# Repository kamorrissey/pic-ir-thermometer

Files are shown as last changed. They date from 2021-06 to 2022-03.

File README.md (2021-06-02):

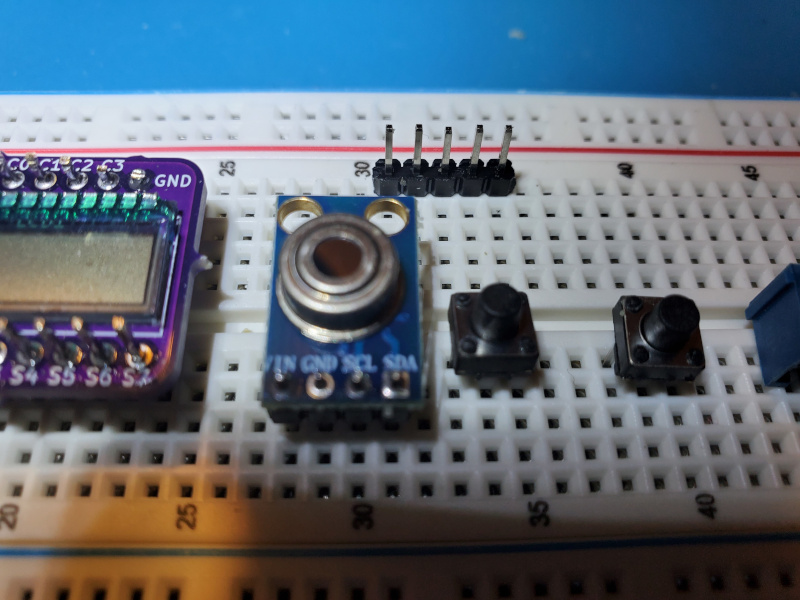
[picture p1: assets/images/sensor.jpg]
MLX90614 IR sensor on breadboard


# pic-ir-thermometer

(Under construction.
Circuit schematic is stable; PCB design to be provided.
Firmware mostly complete but does not yet read from temperature sensor or read/write EEPROM.
3d-printable, handheld enclosure design to be provided.)

Open-source hardware and firmware for a PIC16LF19156-driven IR non-contact thermometer using a Melexis MLX90614 sensor and Lumex LCD-S401M16KR LCD segment display.

This project demonstrates several major functions of a Microchip PIC microcontroller (MCU):
1. using the built-in LCD driver module to directly drive a multiplexed LCD segment display
2. using the I2C/IIC/SMBus interface (MSSP) to communicate with an external temperature sensor
3. using the timer (TMR2, TMR4) and configurable logic cell (CLC) modules to debounce switch inputs in hardware
4. using the timer module (TMR0) to detect timeout of user input
5. using the internal voltage reference (FVR) and analog-to-digital converter (ADC) modules to detect low-battery state with no external components required
6. using the built-in EEPROM to read and write persistent data

The firmware is written in C using the free version of the Microchip MPLAB X IDE and XC8 compiler.
As much code as practical is generated rather than hand-written
by using the Microchip Code Configurator (MCC) plugin-in to MPLAB.
The full MPLAB project is provided.

The hardware uses minimal parts.
The surface mount MOSFET for battery protection is optional.
The full KiCad project containing schematic and PCB design is provided.

A 3D-printable, handheld enclosure design holding a single AA cell is provided.
All needed STL files for printing the enclosure are provided.

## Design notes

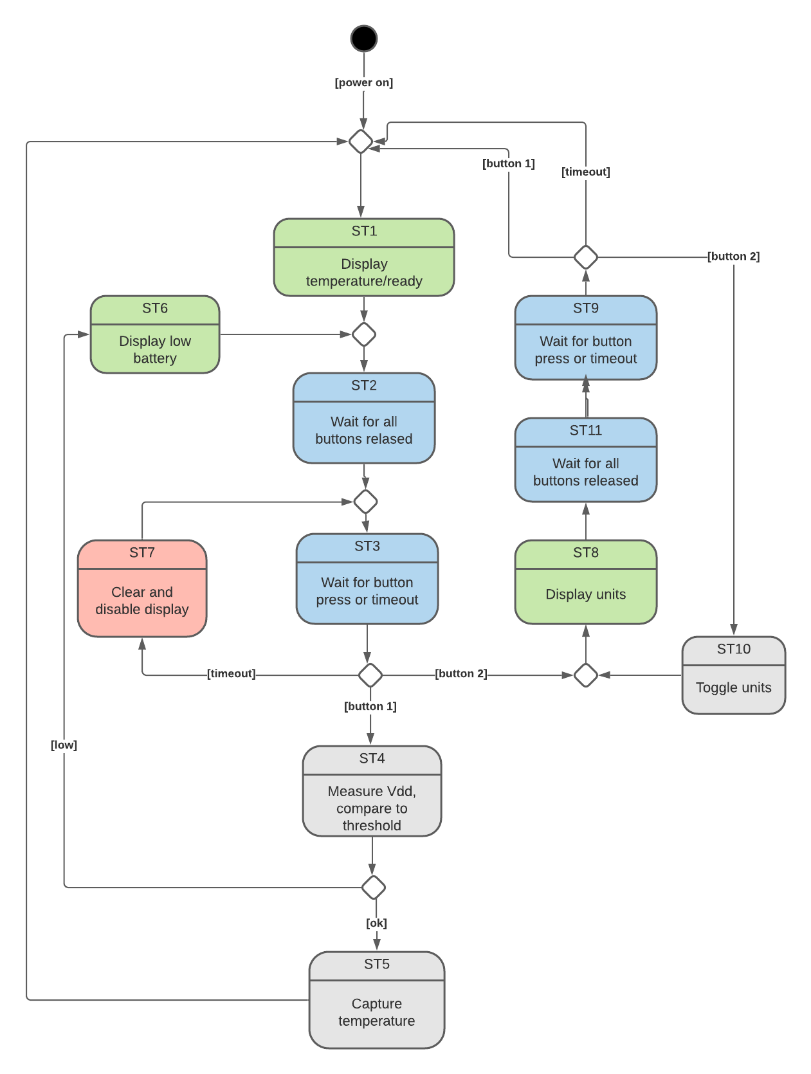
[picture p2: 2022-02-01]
assets/images/Thermometer_State_Diagram.png

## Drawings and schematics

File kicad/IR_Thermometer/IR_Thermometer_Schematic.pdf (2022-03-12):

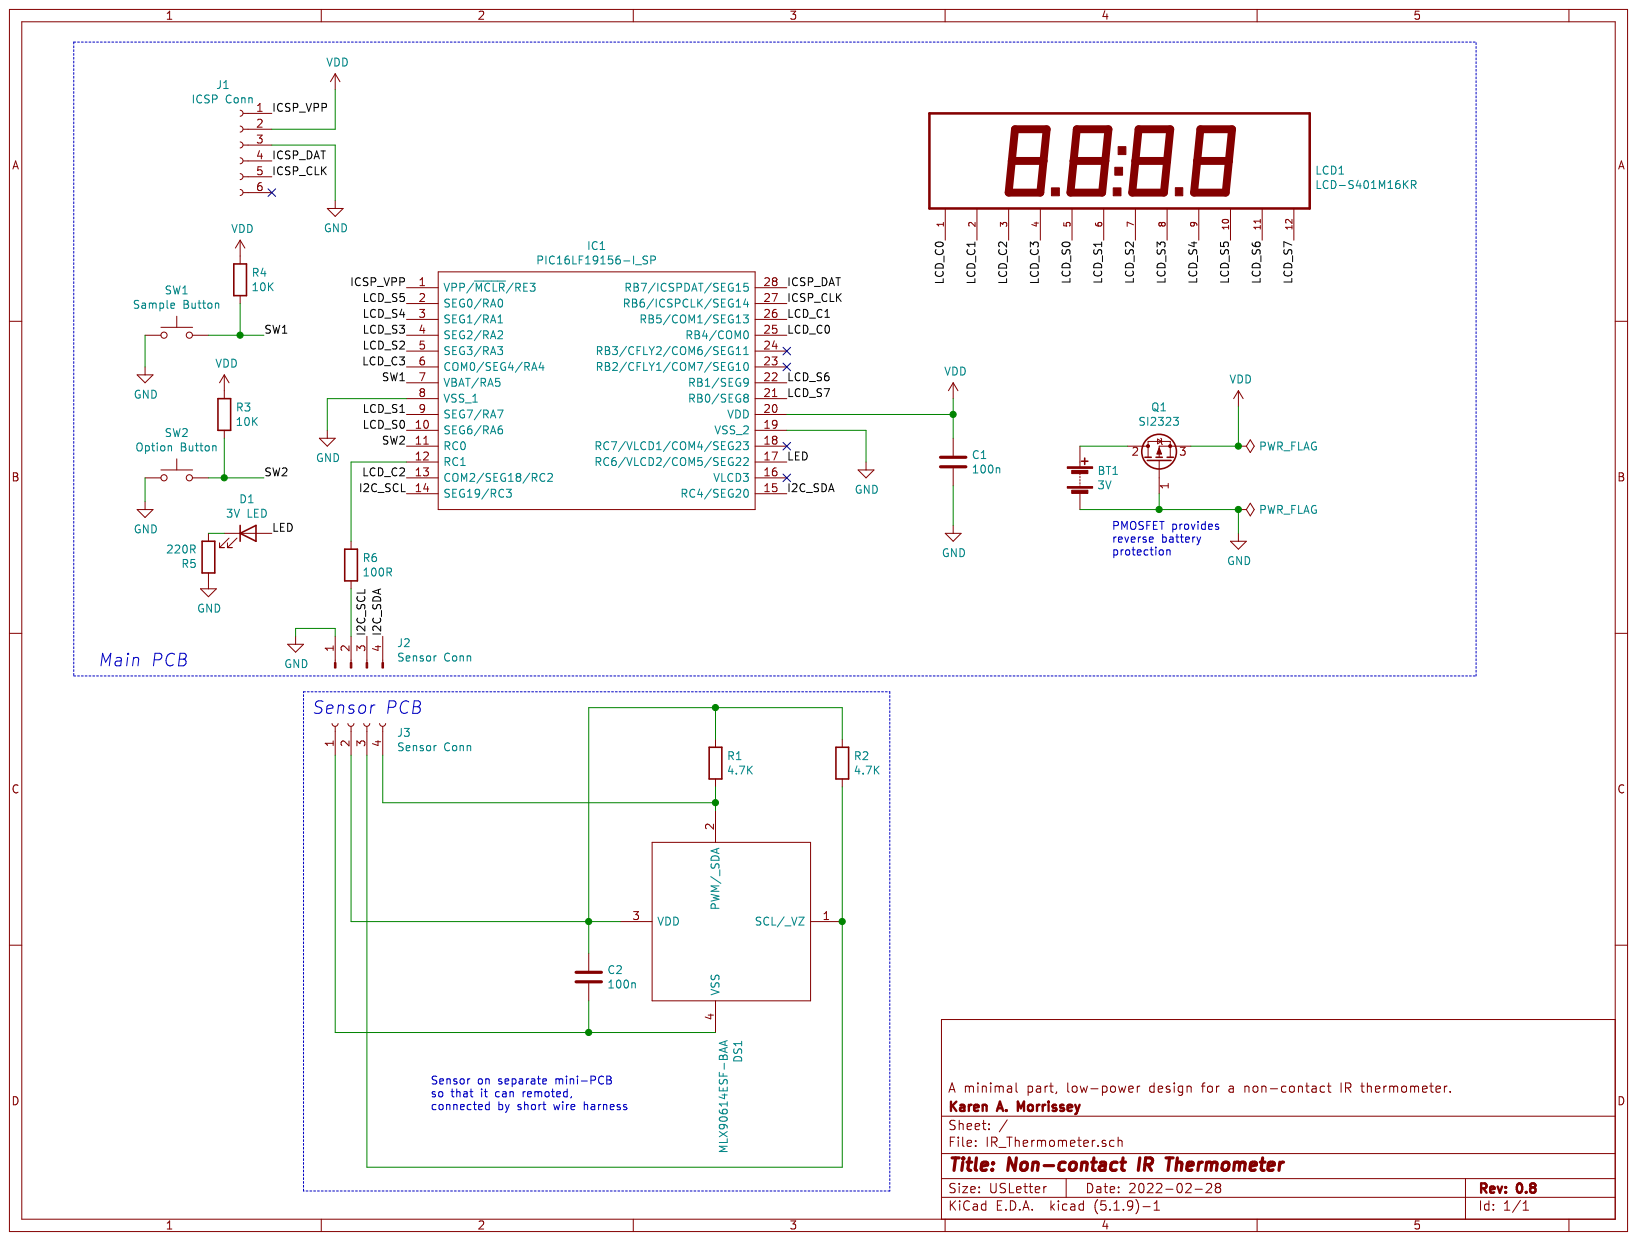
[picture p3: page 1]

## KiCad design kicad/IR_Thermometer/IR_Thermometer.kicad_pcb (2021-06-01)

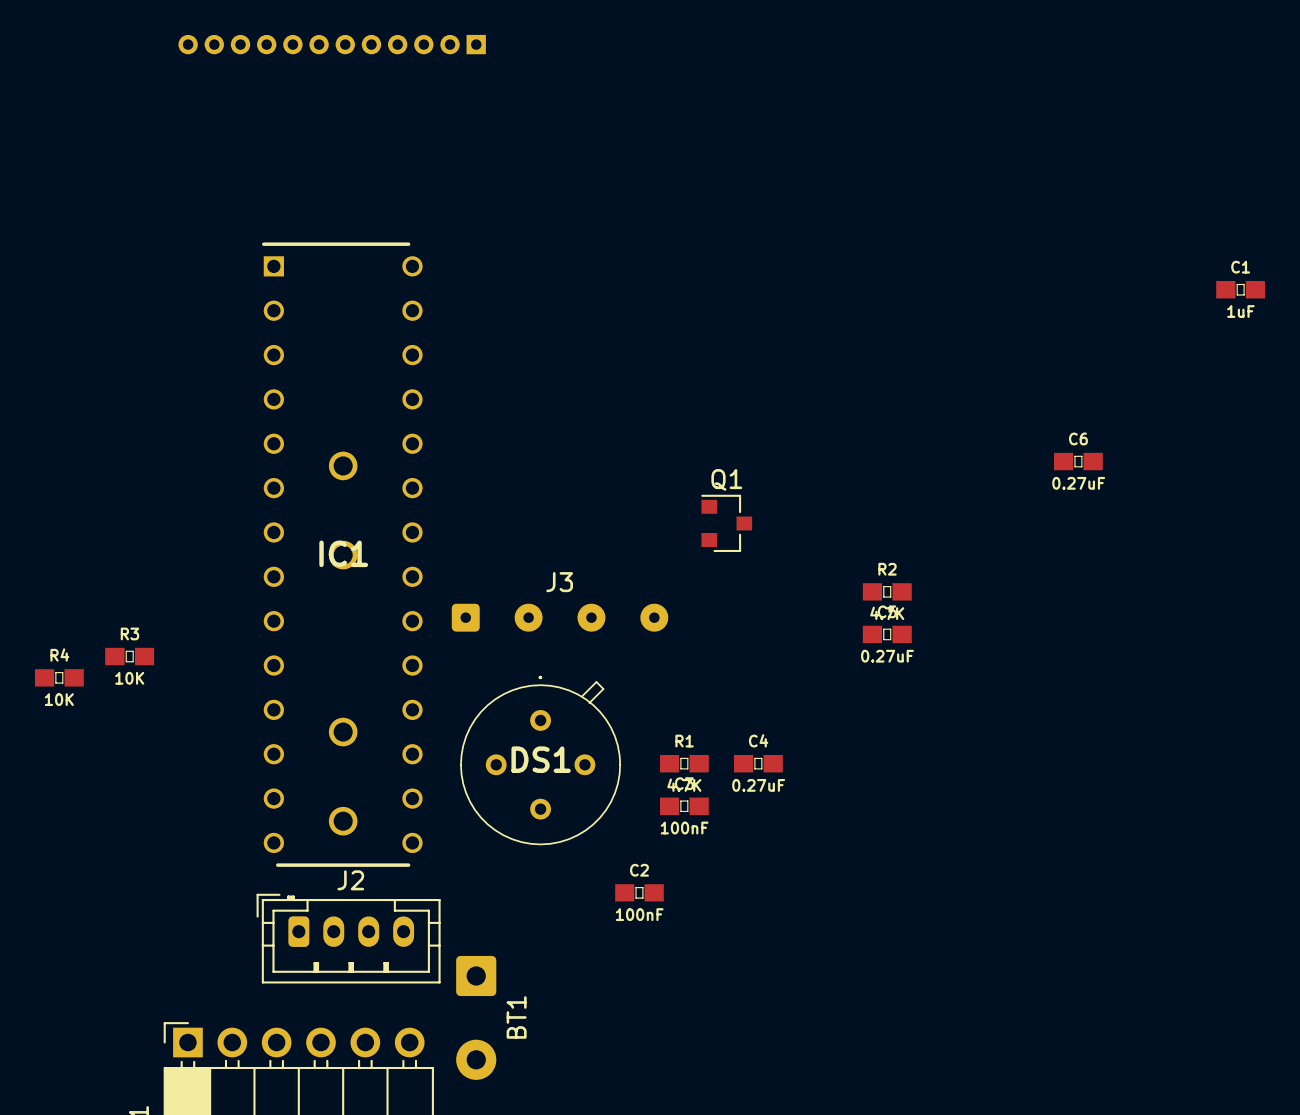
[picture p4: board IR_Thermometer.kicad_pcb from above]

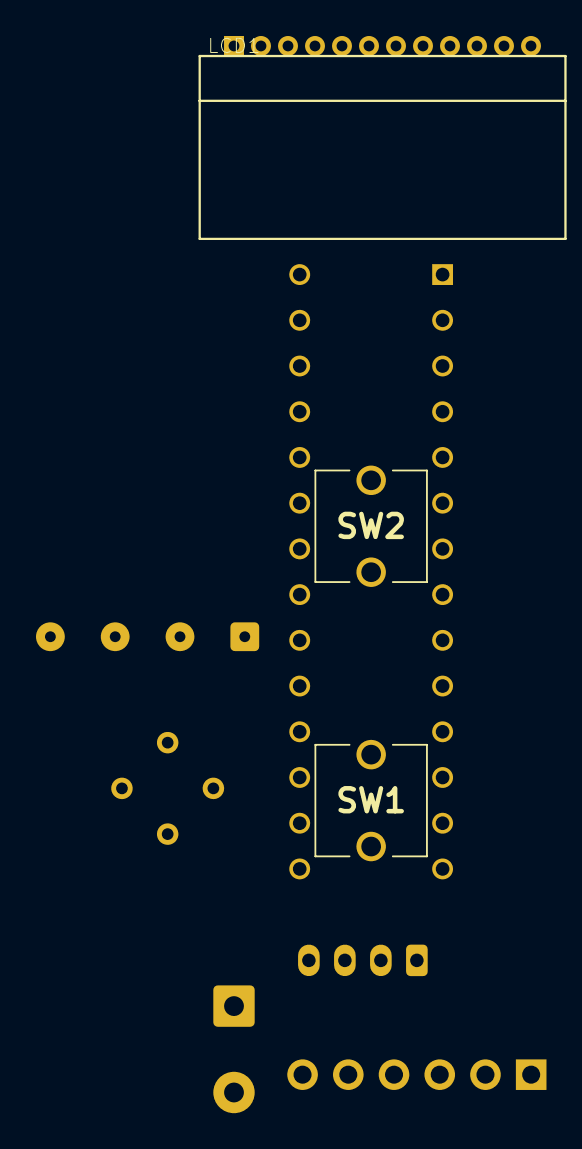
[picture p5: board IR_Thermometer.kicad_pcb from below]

Board: 4 copper layers, 20 parts (3 on the bottom side), 31 nets, no tracks yet.

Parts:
BT1: 3V; SolderWire-0.5sqmm_1x02_P4.8mm_D0.9mm_OD2.3mm
C1: 1uF; 0603
C2, C3: 100nF; 0603
C4, C5, C6: 0.27uF; 0603
DS1: MLX90614ESF-BAA; 1747
IC1: PIC16LF19156-I_SP; DIP794W56P254L3486H508Q28N
J1: ICSP Conn; PinSocket_1x06_P2.54mm_Horizontal
J2: Sensor Conn; JST_PH_B4B-PH-K_1x04_P2.00mm_Vertical
J3: Sensor Conn; SolderWire-0.1sqmm_1x04_P3.6mm_D0.4mm_OD1mm
LCD1: LCD-S401M16KR
Q1: SI2323; SOT-23
R1, R2: 4.7K; 0603
R3, R4: 10K; 0603
SW1: Option Button; FSM2JRT
SW2: Sample Button; FSM2JRT

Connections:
+3V0: C2.1, IC1.20, J1.2, J2.2, Q1.3, R3.1, R4.1
/I2C_SCL: IC1.14, J2.3
/I2C_SDA: IC1.15, J2.4
/ICSP_CLK: IC1.27, J1.5
/ICSP_DAT: IC1.28, J1.4
/ICSP_VPP: IC1.1, J1.1
/LCD_C0: IC1.25, LCD1.1
/LCD_C1: IC1.26, LCD1.2
/LCD_C2: IC1.13, LCD1.3
/LCD_C3: IC1.6, LCD1.4
/LCD_S0: IC1.10, LCD1.5
/LCD_S1: IC1.9, LCD1.6
/LCD_S2: IC1.5, LCD1.7
/LCD_S3: IC1.4, LCD1.8
/LCD_S4: IC1.3, LCD1.9
/LCD_S5: IC1.2, LCD1.10
/LCD_S6: IC1.22, LCD1.11
/LCD_S7: IC1.21, LCD1.12
GND: BT1.2, C2.2, C4.2, C5.2, C6.2, IC1.8, IC1.19, J1.3, J2.1, Q1.1, SW1.1, SW2.1
unnamed: BT1.1, Q1.2
unnamed: C1.1, IC1.24
unnamed: C1.2, IC1.23
unnamed: C3.1, DS1.3, J3.2, R1.1, R2.1
unnamed: C3.2, DS1.4, J3.1
unnamed: C4.1, IC1.16
unnamed: C5.1, IC1.17
unnamed: C6.1, IC1.18
unnamed: DS1.1, J3.3, R2.2
unnamed: DS1.2, J3.4, R1.2
unnamed: IC1.7, R4.2, SW2.2
unnamed: IC1.11, R3.2, SW1.2

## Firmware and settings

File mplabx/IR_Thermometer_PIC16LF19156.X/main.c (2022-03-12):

/**
  Generated Main Source File

  Company:
    Microchip Technology Inc.

  File Name:
    main.c

  Summary:
    This is the main file generated using PIC10 / PIC12 / PIC16 / PIC18 MCUs

  Description:
    This header file provides implementations for driver APIs for all modules selected in the GUI.
    Generation Information :
        Product Revision  :  PIC10 / PIC12 / PIC16 / PIC18 MCUs - 1.81.7
        Device            :  PIC16LF19156
        Driver Version    :  2.00
*/

/*
    (c) 2018 Microchip Technology Inc. and its subsidiaries. 
    
    Subject to your compliance with these terms, you may use Microchip software and any 
    derivatives exclusively with Microchip products. It is your responsibility to comply with third party 
    license terms applicable to your use of third party software (including open source software) that 
    may accompany Microchip software.
    
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
    IN NO EVENT WILL MICROCHIP BE LIABLE FOR ANY INDIRECT, SPECIAL, PUNITIVE, 
    INCIDENTAL OR CONSEQUENTIAL LOSS, DAMAGE, COST OR EXPENSE OF ANY KIND 
    WHATSOEVER RELATED TO THE SOFTWARE, HOWEVER CAUSED, EVEN IF MICROCHIP 
    HAS BEEN ADVISED OF THE POSSIBILITY OR THE DAMAGES ARE FORESEEABLE. TO 
    THE FULLEST EXTENT ALLOWED BY LAW, MICROCHIP'S TOTAL LIABILITY ON ALL 
    CLAIMS IN ANY WAY RELATED TO THIS SOFTWARE WILL NOT EXCEED THE AMOUNT 
    OF FEES, IF ANY, THAT YOU HAVE PAID DIRECTLY TO MICROCHIP FOR THIS 
    SOFTWARE.
*/

#include <xc.h>
#include "mcc_generated_files/mcc.h"
#include "display.h"
#include "mlx90614.h"

#define DATAEE_BLOCK_BASE 0xF000
#define LOW_VOLTAGE_THRESHOLD 2650  // millivolts
#define IDLE_TIMEOUT_TICKS 300      // secs * 10 ticks/sec

typedef enum sm_state {
    ST1, ST2, ST3, ST4, ST5,
    ST6, ST7, ST8, ST9, ST10,
    ST11,
} SM_STATE_ENUM;

typedef enum temp_mode {
    FAHRENHEIT,
    CELSIUS,
} TEMP_MODE_ENUM;

typedef enum button {
    BUTTON_1,
    BUTTON_2,
} BUTTON_ENUM;


typedef struct dataee_block {
    uint8_t temp_mode;
} DATAEE_BLOCK;

typedef struct app_state {
    DATAEE_BLOCK dataee_block;
    uint8_t temp_exists;
    float temp_C;
    volatile int16_t ticks_remaining;
    SM_STATE_ENUM next_sm_state;
} APP_STATE;

APP_STATE g_app_state; // global state information

// forward references
void App_Initialize(void);
inline void App_GotoState( SM_STATE_ENUM new_state );
void App_OnTimerClick(void);
void App_DisplayTemp(void);
inline bool App_ButtonPressed_1(void);
inline bool App_ButtonPressed_2(void);
inline void App_WaitButtonsReleased(void);
void App_RunST1(void);
void App_RunST2(void);
void App_RunST3(void);
void App_RunST4(void);
void App_RunST5(void);
void App_RunST6(void);
void App_RunST7(void);
void App_RunST8(void);
void App_RunST9(void);
void App_RunST10(void);
void App_RunST11(void);

int32_t Get_SupplyVoltage(void);
float Get_Temperature(void);
void DataEE_Load( DATAEE_BLOCK* buffer );
void DataEE_Store( DATAEE_BLOCK* buffer );

void PMD_UnusedDisable(void);
void PMD_Sleep(void);
void PMD_Wake(void);

/*
                         Main application
 */
void main(void)
{
    // initialize the device
    SYSTEM_Initialize();

    // When using interrupts, you need to set the Global and Peripheral Interrupt Enable bits
    // Use the following macros to:

    // Enable the Global Interrupts
    INTERRUPT_GlobalInterruptEnable();

    // Enable the Peripheral Interrupts
    INTERRUPT_PeripheralInterruptEnable();

    // Disable the Global Interrupts
    //INTERRUPT_GlobalInterruptDisable();

    // Disable the Peripheral Interrupts
    //INTERRUPT_PeripheralInterruptDisable();
        
    App_Initialize();
    TMR0_SetInterruptHandler( App_OnTimerClick );
    
    while (1)
    {
        switch (g_app_state.next_sm_state)
        {
        default:
        case ST1:
            App_RunST1();
            break;
        case ST2:
            App_RunST2();
            break;
        case ST3:
            App_RunST3();
            break;
        case ST4:
            App_RunST4();
            break;
        case ST5:
            App_RunST5();
            break;
        case ST6:
            App_RunST6();
            break;
        case ST7:
            App_RunST7();
            break;
        case ST8:
            App_RunST8();
            break;
        case ST9:
            App_RunST9();
            break;
        case ST10:
            App_RunST10();
            break;
        case ST11:
            App_RunST11();
            break;
       }
    }
}

// Returns estimate of Vdd in millivolts
int32_t Get_SupplyVoltage(void)
{
    while (!FVR_IsOutputReady());
    ADCC_StartConversion(channel_FVR_Buffer1);
    while(!ADCC_IsConversionDone());
    uint16_t adc = ADCC_GetConversionResult();
    int32_t supply_voltage = ( 1024L * 4096L ) / adc;
    return supply_voltage;
}

float Get_Temperature(void)
{
    int32_t temp = MlxReadObjectTemp();
    return temp / 100.0f;
}

void App_Initialize(void)
{
    App_GotoState( ST1 );
    PMD_UnusedDisable();
    DataEE_Load(&g_app_state.dataee_block);
    g_app_state.temp_exists = 0;
    g_app_state.temp_C = 0.0f;
    DISPLAY_AllPixels_On();
    MlxWake();
}

inline void App_GotoState( SM_STATE_ENUM sm_state )
{
    TMR0_StopTimer();
    g_app_state.next_sm_state = sm_state;
    g_app_state.ticks_remaining = 0;
}

void App_OnTimerClick(void)
{
    if ( g_app_state.ticks_remaining > 0 )
    {
        --g_app_state.ticks_remaining;
    }
}

void App_DisplayTemp(void)
{
    if ( !g_app_state.temp_exists )
    {
        DISPLAY_Ready();
    }
    else
    {
        int16_t temp;
        if ( g_app_state.dataee_block.temp_mode == FAHRENHEIT )
        {
            temp = (int16_t)(10 * ( g_app_state.temp_C * 9 / 5 + 32 ) + 0.5);
        }
        else
        {
            temp = (int16_t)(10 * g_app_state.temp_C + 0.5);
        }
        DISPLAY_ShowNumber( temp, 1 );
    }
}

inline bool App_ButtonPressed_1(void)
{
    return CLC1_OutputStatusGet();
}

inline bool App_ButtonPressed_2(void)
{
    return CLC2_OutputStatusGet();
}

inline void App_WaitButtonsReleased(void)
{
    // Wait for all buttons released
    while ( App_ButtonPressed_1() || App_ButtonPressed_2() )
    {
        SLEEP();
    }
}

void App_RunST1(void)
{
    // Display temperature or ready-indicator
    LCD_Enable();
    App_DisplayTemp();
    App_GotoState( ST2 );
}

void App_RunST2(void)
{
    App_WaitButtonsReleased();
    App_GotoState( ST3 );
}

void App_RunST3(void)
{
    // Wait for button press or timeout
    g_app_state.ticks_remaining = IDLE_TIMEOUT_TICKS;
    TMR0_Reload();
    TMR0_StartTimer();
    while (1)
    {
        if ( App_ButtonPressed_1() )
        {
            TMR0_StopTimer();
            App_GotoState( ST4 );
            return;
        }
        else if ( App_ButtonPressed_2() )
        {
            TMR0_StopTimer();
            App_GotoState( ST8 );
            return;
        }
        else if ( g_app_state.ticks_remaining == 0 )
        {
            TMR0_StopTimer();
            App_GotoState( ST7 );
            return;
        }
        else
        {
            SLEEP();
        }
    }
}

void App_RunST4(void)
{
    // Measure Vdd in millivolts, compare to threshold
    int32_t vdd = Get_SupplyVoltage();
    if ( vdd < LOW_VOLTAGE_THRESHOLD )
    {
        App_GotoState( ST6 );
    }
    else
    {
        App_GotoState( ST5 );
    }
}

void App_RunST5(void)
{
    // Capture temperature
    g_app_state.temp_C = Get_Temperature();
    g_app_state.temp_exists = 1;
    App_GotoState( ST1 );
}

void App_RunST6(void)
{
    // Display low battery
    LCD_Enable();
    DISPLAY_BatteryLow();
    App_GotoState( ST2 );
}

void App_RunST7(void)
{
    App_WaitButtonsReleased();
    // Clear display and put it to sleep
    DISPLAY_AllPixels_Off();
    LCD_Disable();
    MlxSleep();
    PMD_Sleep();
    // sleep CPU until button1/2 pressed
    while (1)
    {
        if ( App_ButtonPressed_1() )
        {
            PMD_Wake();
            DISPLAY_AllPixels_On();
            MlxWake();
            App_GotoState( ST4 );
            return;
        }
        else if ( App_ButtonPressed_2() )
        {
            PMD_Wake();
            DISPLAY_AllPixels_On();
            MlxWake();
            App_GotoState( ST8 );
            return;
        }
        SLEEP();
    }
}

void App_RunST8(void)
{
    // Display units
    LCD_Enable();
    DISPLAY_DIG1_Segments( DISPLAY_CharToSegments(' '));
    DISPLAY_DIG2_Segments( DISPLAY_CharToSegments(' '));
    DISPLAY_DIG3_Segments( DISPLAY_CharToSegments(' '));
    if ( g_app_state.dataee_block.temp_mode == FAHRENHEIT )
    {
        DISPLAY_DIG4_Segments( DISPLAY_CharToSegments('F'));
    }
    else
    {
        DISPLAY_DIG4_Segments( DISPLAY_CharToSegments('C'));
    }
    DISPLAY_DP1_Off();
    DISPLAY_DP2_Off();
    DISPLAY_DP3_Off();
    DISPLAY_COLON_Off();
    App_GotoState( ST11 );
}

void App_RunST9(void)
{
    // Wait for button press or timeout
    g_app_state.ticks_remaining = 50; // 5 secs
    TMR0_Reload();
    TMR0_StartTimer();
    while (1)
    {
        if ( App_ButtonPressed_1() )
        {
            App_GotoState( ST1 );
            return;
        }
        else if ( App_ButtonPressed_2() )
        {
            App_GotoState( ST10 );
            return;
        }
        else if ( g_app_state.ticks_remaining == 0 )
        {
            App_GotoState( ST1 );
            return;
        }
        else
        {
            SLEEP();
        }
    }
}

void App_RunST10(void)
{
    // Toggle units
    if ( g_app_state.dataee_block.temp_mode == FAHRENHEIT )
    {
        g_app_state.dataee_block.temp_mode = CELSIUS;
    }
    else
    {
        g_app_state.dataee_block.temp_mode = FAHRENHEIT;
    }
    // TODO: save units to EEPROM
    DataEE_Store(&g_app_state.dataee_block);
    App_GotoState( ST8 );
}

void App_RunST11(void)
{
    App_WaitButtonsReleased();
    App_GotoState( ST9 );
}

void DataEE_Load( DATAEE_BLOCK* buffer )
{
    uint8_t* dest = (uint8_t*)buffer;
    for ( uint16_t i = 0; i < sizeof(DATAEE_BLOCK); ++i )
    {
        *dest++ = DATAEE_ReadByte( DATAEE_BLOCK_BASE + i );
    }
}

void DataEE_Store( DATAEE_BLOCK* buffer )
{
    uint8_t* src = (uint8_t*)buffer;
    for ( uint16_t i = 0; i < sizeof(DATAEE_BLOCK); ++i )
    {
        DATAEE_WriteByte( DATAEE_BLOCK_BASE + i, *src++ );
    }
}

void PMD_UnusedDisable(void)
{
    PMD0bits.ACTMD = 1;
    // PMD0bits.FVRMD = 1;
    PMD0bits.IOCMD = 1;
    // PMD0bits.NVMMD = 1;
    // PMD0bits.SYSCMD = 1;
    
    // PMD1bits.TMR0MD = 1;
    // PMD1bits.TMR1MD = 1;
    // PMD1bits.TMR2MD = 1;
    // PMD1bits.TMR4MD = 1;

    // PMD2bits.ADCMD = 1;
    PMD2bits.CMP1MD = 1;
    PMD2bits.CMP2MD = 1;
    PMD2bits.DACMD = 1;
    PMD2bits.RTCCMD = 1;
    PMD2bits.ZCDMD = 1;
    
    PMD3bits.CCP1MD = 1;
    PMD3bits.CCP2MD = 1;
    PMD3bits.CCP3MD = 1; // PWM3
    PMD3bits.CCP4MD = 1; // PWM4
    
    PMD4bits.CWG1MD = 1;
    // PMD4bits.MSSP1MD = 1;
    PMD4bits.UART1MD = 1;
    PMD4bits.UART2MD = 1;
    
    // PMD5bits.CLC1MD = 1;
    // PMD5bits.CLC2MD = 1;
    // PMD5bits.CLC3MD = 1;
    // PMD5bits.CLC4MD = 1;
    // PMD5bits.LCDMD = 1;
    // PMD5bits.SMT1MD = 1;
}

void PMD_Sleep(void)
{
    FVREN = 0;
}

void PMD_Wake(void)
{
    FVREN = 1;
}

/**
 End of File
*/

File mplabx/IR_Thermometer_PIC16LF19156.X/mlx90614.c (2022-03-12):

/* 
 * File:   mlx90614.c
 * Author: kamor
 *
 * Created on January 28, 2022, 10:31 PM
 */

#include <xc.h>

#include "mcc_generated_files/examples/i2c1_master_example.h"
#include "mcc_generated_files/mcc.h"
#include "mlx90614.h"

// Uncomment this define to stub out IR sensor
//#define NO_SENSOR

#define MLX_BUS_ADDR 0x5A   // Default I2C bus address for MLX90614
#define RAMADDR_TAMB 6      // Address from which to read ambient (sensor's own) temperature.
#define RAMADDR_TOBJ 7      // Address from which to read object (person's) temperature.
#define ADDR_SLEEP 0xFF     // Address for sleep command
#define PEC_SLEEP 0xE8      // Error check code for sleep command


// crc8 is adapted from https://github.com/sparkfun/SparkFun_MLX90614_Arduino_Library/blob/master/src/SparkFunMLX90614.cpp
static uint8_t crc8 (uint8_t inCrc, uint8_t inData)
{
	uint8_t data = inCrc ^ inData;
	for (uint8_t i = 0; i < 8; i++)	{
		if (( data & 0x80 ) != 0 ) {
			data <<= 1;
			data ^= 0x07;
		} else {
			data <<= 1;
		}
	}
	return data;
}

int32_t MlxReadObjectTemp(void)
{
#ifdef NO_SENSOR
    static uint8_t count = 0;
    static int32_t temp[] = { 3700, 3650, 3750, };
    if ( count >= 3 )
    {
        count = 0;
    }
    return temp[count++];
#else
    uint8_t bus_addr = MLX_BUS_ADDR;
    // TODO: implement error handling on sensor read
    uint16_t raw = I2C1_Read2ByteRegister(bus_addr, RAMADDR_TOBJ);
    // Have to swap bytes in answer
    uint16_t normalized = (raw << 8 | raw >> 8);
    // normalized is centiK, convert to centiC
    return normalized * 2L - 27315;
#endif
}

void MlxSleep(void)
{
    // Turn off power to sensor
    MLX_PWR_SetLow();
}

void MlxWake(void)
{
    // Turn on power to sensor
    MLX_PWR_SetHigh();
    // sleep 300ms, waiting for sensor to initialize (0.25s nominal)
    __delay_ms(300);
    // Get a temp reading because 1st one after sensor init will be raw
    (void)MlxReadObjectTemp();
}

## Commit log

2021-06-02 Fix units display and button handling
    [main.c]
2021-06-02 Fix button2 release error
    [main.c]
2021-06-17 Updates to schematic
    [IR_Thermometer.sch]
2022-02-01 Read from MLX90614 sensor
2022-03-12 Sleep mode implementation
    [IR_Thermometer.kicad_sch, IR_Thermometer.sch]
